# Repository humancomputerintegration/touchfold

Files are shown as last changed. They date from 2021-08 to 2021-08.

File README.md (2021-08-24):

# Touch&Fold: A Foldable Haptic Actuator for Rendering Touch in Mixed Reality

This is the repository for PCB schematics and 3D printed file used in the wearable device in the "Touch&Fold: A Foldable Haptic Actuator for Rendering Touch in Mixed Reality" paper (ACM CHI2021).

## hardware

- DC motor (26:1 Sub-Micro Planetary Gearmotor 0.1 kg-cm, Pololu)
- linear resonant actuator (LRA C10-100, Precision Micro Drives)
- force sensor (FSR 400, Interlink Electronics)
- photo interrupter (SG-105F, Kodenshi)

## citing

When using or building upon this device in an academic publication, please consider citing as follows:

Shan-Yuan Teng, Pengyu Li, Romain Nith, Joshua Fonseca, Pedro Lopes. 2021. Touch&Fold: A Foldable Haptic Actuator for Rendering Touch in Mixed Reality. In Proceedings of CHI Conference on Human Factors in Computing Systems 2021 (CHI’2021). Association for Computing Machinery, New York, NY, USA.  https://doi.org/10.1145/3411764.3445099

## thanks / acknowledgments

We would like to thank our colleague Daniel Steinberg for assisting us in building a Project North Star headset. Secondly, we would like to thank Leap Motion for open-sourcing the aforementioned mixed reality headset and Microsoft for open-sourcing the Mixed Reality Toolkit. Moreover, we would like to thank the University of Chicago’s The Center for Data and Computing (CDAC) for their support with the HoloLens headset. Lastly, we sincerely thank our funding sources for making this work possible. We would like to thank the University of Chicago’s Center for Unstoppable Computing (CERES) for their on-going support. Lastly, this work was supported by the Sony Research Award program.

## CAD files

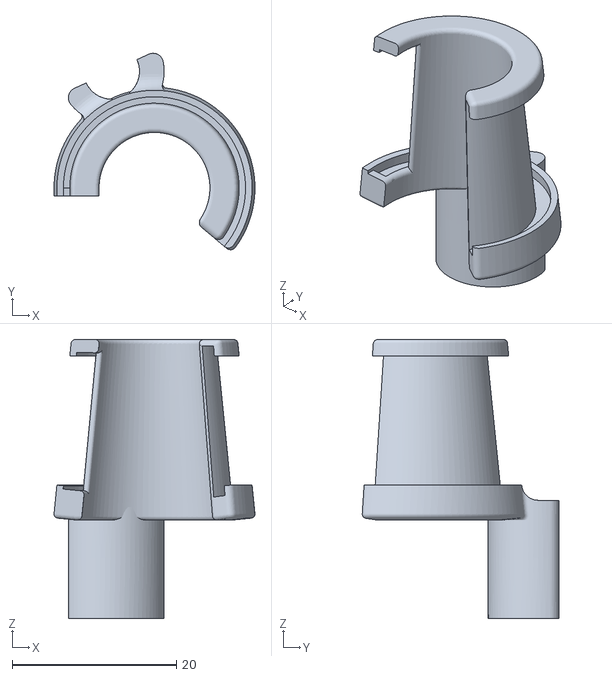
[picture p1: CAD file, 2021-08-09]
3D-print models/main_case.stl
24.5 x 23.9 x 34.0

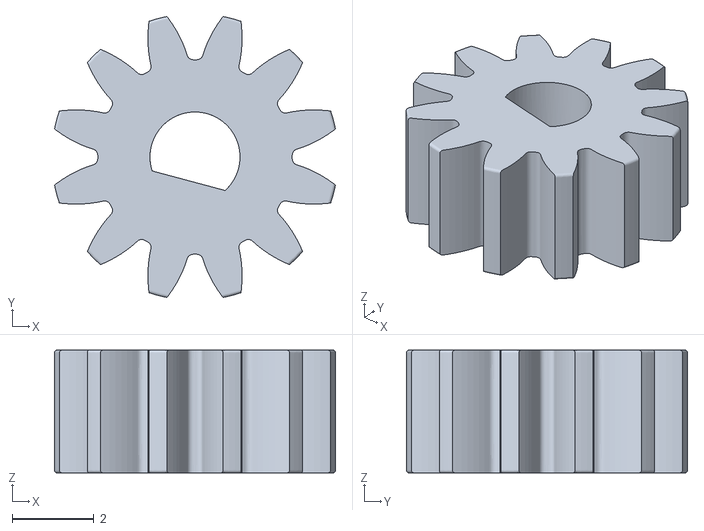
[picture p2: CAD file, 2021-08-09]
3D-print models/gear.stl
6.86 x 6.86 x 3.00

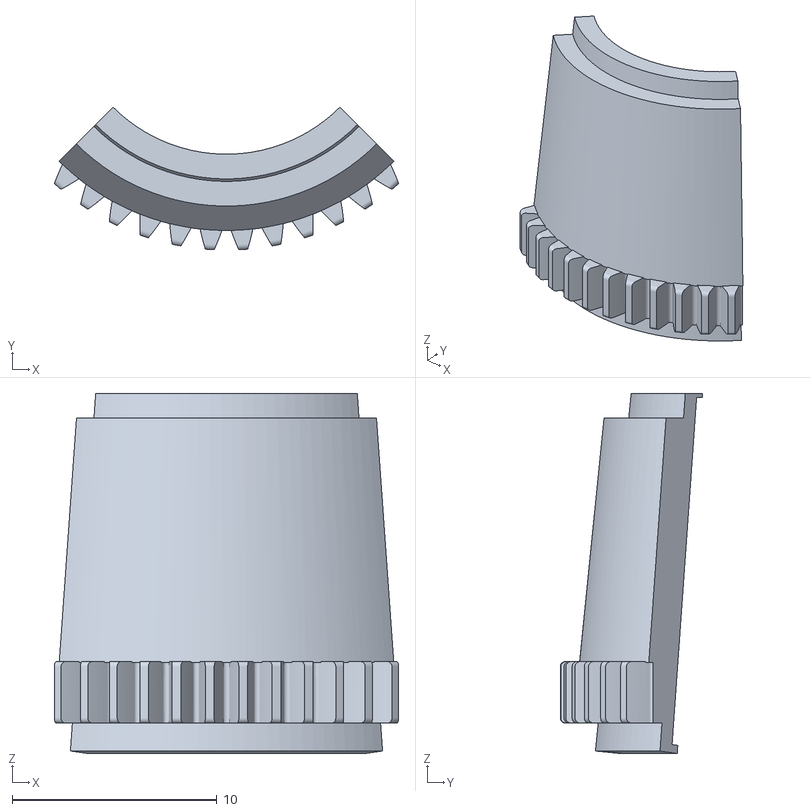
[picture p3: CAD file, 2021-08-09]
3D-print models/cover_rear.stl
16.8 x 6.95 x 17.6

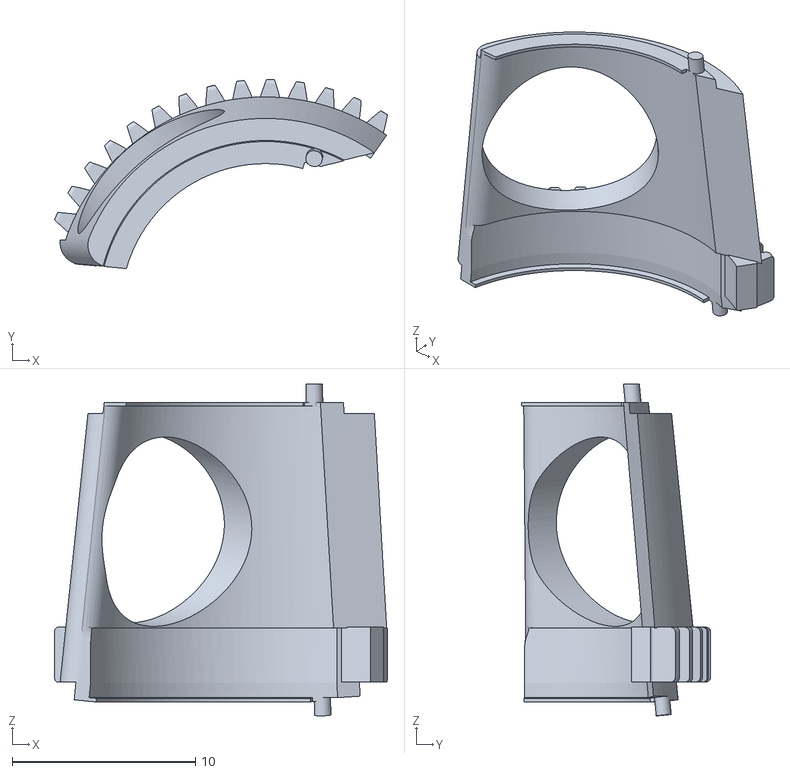
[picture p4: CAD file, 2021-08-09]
3D-print models/cover_front.stl
18.2 x 10.3 x 18.1

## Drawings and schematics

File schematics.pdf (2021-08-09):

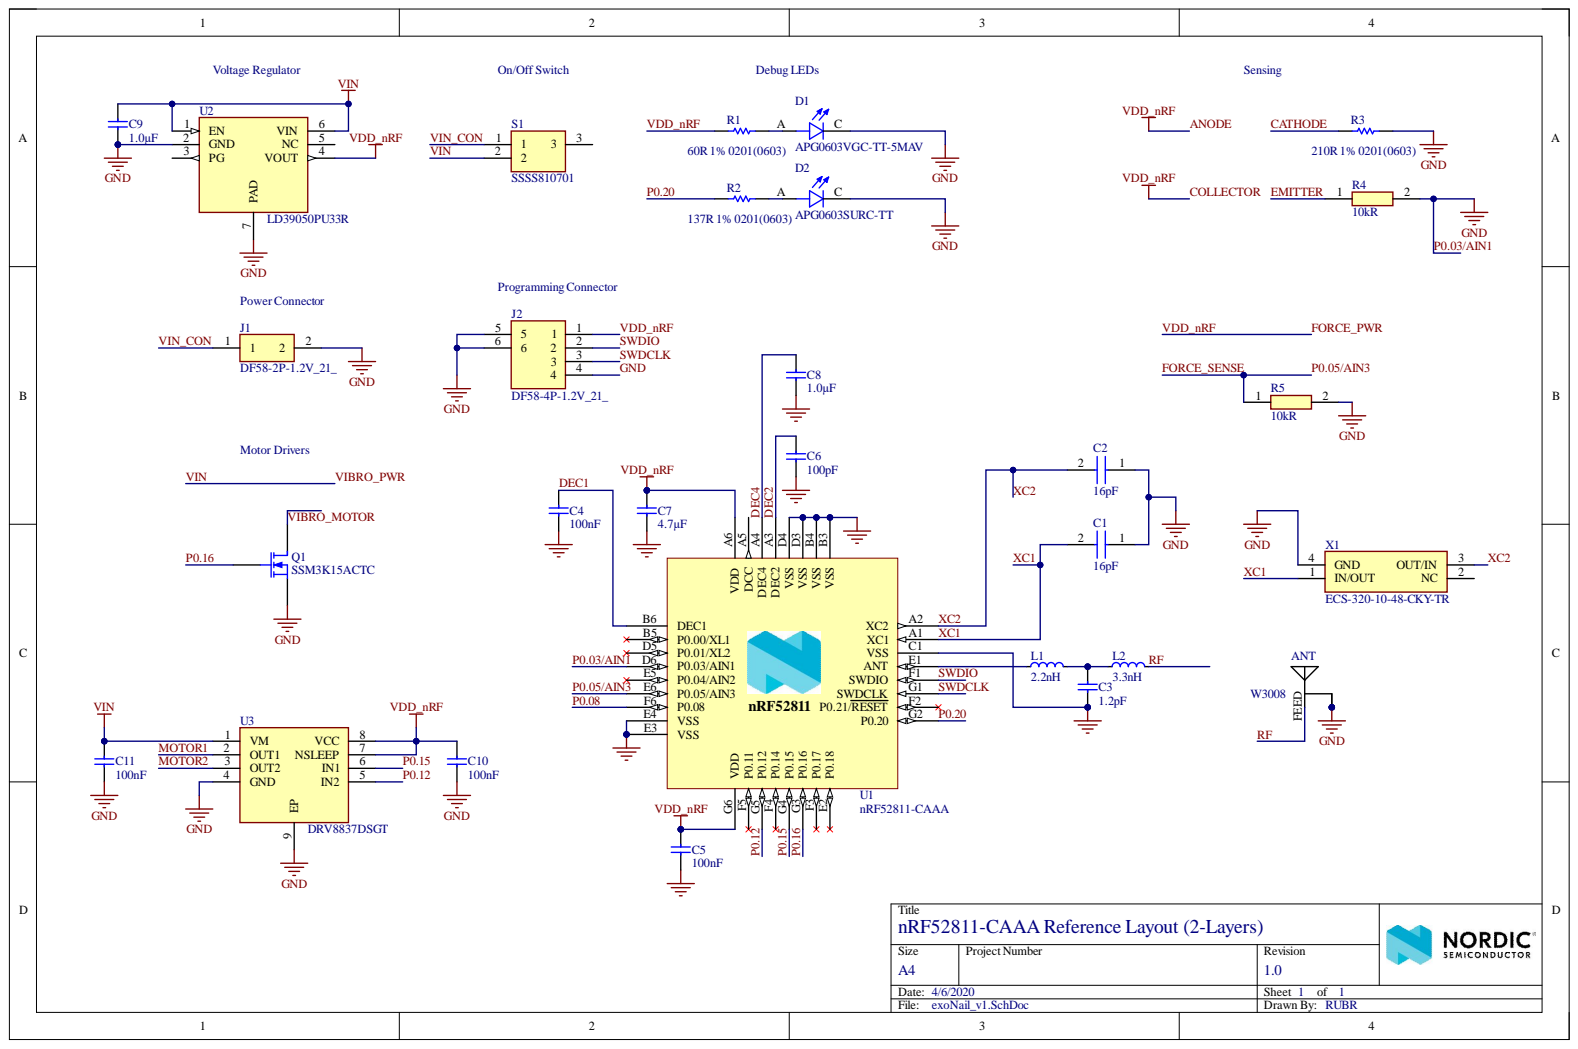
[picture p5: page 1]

Title nRF52811-CAAA Reference Layout (2-Layers)

Size A4 | Project Number | Revision 1.0

Date: 4/6/2020 | Sheet 1 of 1
File: exoNail_v1.SchDoc | Drawn By: RUBR

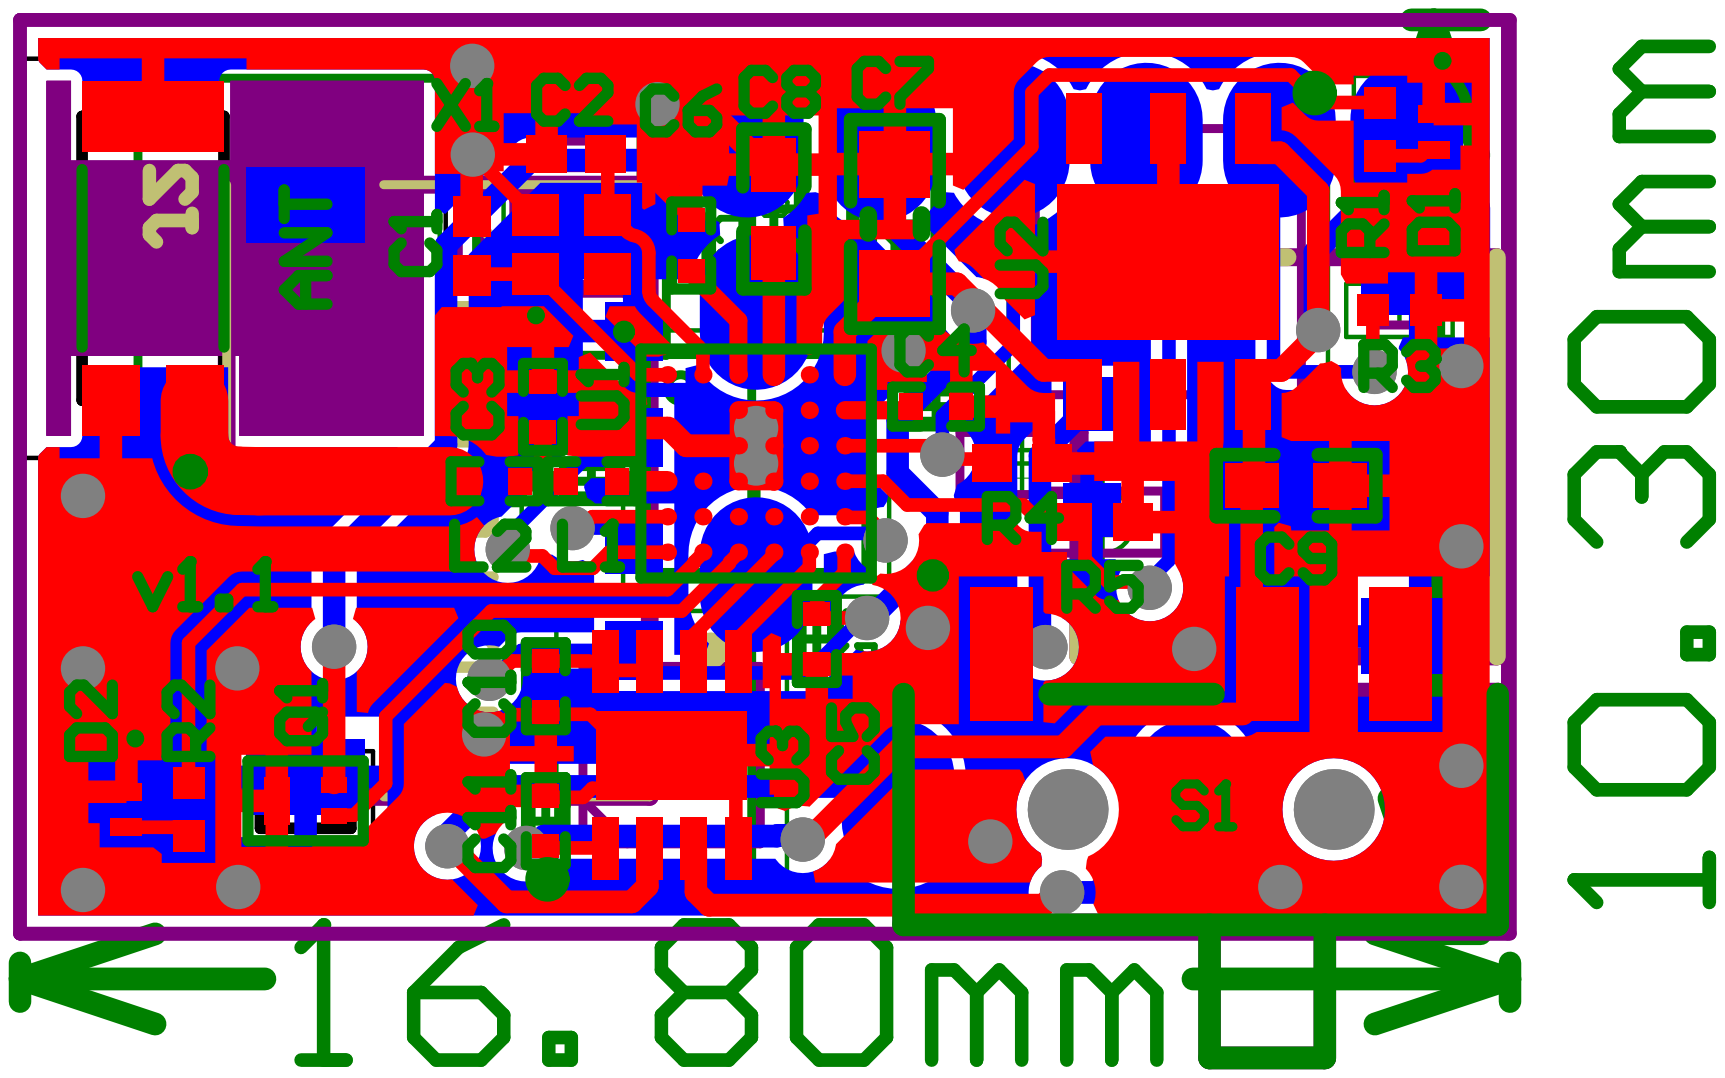
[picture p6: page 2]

Comment | Description | Designator | Footprint | LibRef | Quantity
W3008 | 2.4GHz Bluetooth Chip RF Antenna 2.4GHz ~ 2.483GHz 1.7dBi Solder Surface Mount | ANT | *ANTENNA_W3008W 3008(Primary) | W3008 | 1
16pF | Capacitor | C1, C2 | CAPC0603X33N | GRM0335C1H160JA01 D | 2
1.2pF | Capacitor, NP0, ±5% | C3 | CAPC0603X03L_C | C0201-1.2p | 1
100nF | Capacitor, X5R, ±10% | C4, C5, C10, C11 | CAPC0603X03L_C | C0201-100n, [NoValue] | 4
100pF | Capacitor, NP0, ±2% | C6 | CAPC0603X03L_C | C0201-100p | 1
4.7µF | Capacitor, X5R, ±10% | C7 | CAPC1608X06L | C0603-4µ7 | 1
1.0µF | Capacitor, X5R, ±5% | C8, C9 | CAPC1005X04L | C0402-1µ0 | 2
APG0603VGC-TT-5MAV | Green 527nm LED Indication - Discrete 3V 2-SMD, 0201 | D1 | LED_APG0603SEC-E-TT | APG0603SEC-E-TT | 1
APG0603SURC-TT | Red 631nm LED Indication - Discrete 1.92V 2-SMD, 0201 | D2 | LED_APG0603SEC-E-TT | APG0603SEC-E-TT | 1
DF58-2P-1.2V_21_ | Connector | J1 | DF58-2P-1.2V(21) | DF58-2P-1.2V_21_ | 1
DF58-4P-1.2V_21_ | Connector | J2 | DF584P12V21 | DF58-4P-1.2V_21_ | 1
2.2nH | High frequency chip inductor ±5% | L1 | INDC0603X03L_C | L0201-2n2 | 1
3.3nH | High frequency chip inductor ±5% | L2 | INDC0603X03L_C | L0201-3n3 | 1
SSM3K15ACTC | N-Channel MOSFET -SSM3K15ACTC | Q1 | *DFN985X585X50-3N | MOSFET-N | 1
60R 1% 0201(0603) | 1R 0.05W 1% 0201 (0603 Metric) SMD | R1 | RESC0201(0603)_L | CMP-1010-00171-1 | 1
137R 1% 0201(0603) | 1R 0.05W 1% 0201 (0603 Metric) SMD | R2 | RESC0201(0603)_L | CMP-1010-00171-1 | 1
210R 1% 0201(0603) | 210R 0.05W 1% 0201 (0603 Metric) SMD | R3 | RESC0201(0603)_L | CMP-1010-00171-1 | 1
10kR | Resistor | R4, R5 | RESC0603X26N | RC0201FR-07100KL | 2
SSSS810701 | Switch | S1 | SSSS810701 | SSSS810701 | 1
nRF52811-CAAA | Multi-protocol Bluetooth Low Energy, IEEE 802.15.4, ANT and 2.4GHz proprietary system-on-chip | U1 | BGA33C40P6X6_247X 246X50 | nRF52811-CAAAA0 | 1
LD39050PU33R | Power Supply | U2 | SON95P300X300X100-7N-D | LD39050PU33R | 1
DRV8837DSGT | Integrated Circuit | U3 | SON50P200X200X80-9N | DRV8837DSGT | 1
ECS-320-10-48-CKY-TR | Crystal or Oscillator | X1 | ECS240848CKYTR | ECS-320-10-48-CKY-TR | 1
